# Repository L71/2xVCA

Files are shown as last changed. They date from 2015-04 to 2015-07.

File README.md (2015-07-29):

2 channel VCA module for Eurorack. 

LM13700 based VCA. Two separate channels. 
The VCA CV input is biased to about 8V when no plug is in the CV input (so VCA is open). 

This PCB and front panel drawings are released under the Creative Commons CC-BY-SA 4.0 license.

** Note: the SMD version of the module has the potentionmeters in the opposite direction of the usual. Use knobs that match (or pots with round or T18 shafts).

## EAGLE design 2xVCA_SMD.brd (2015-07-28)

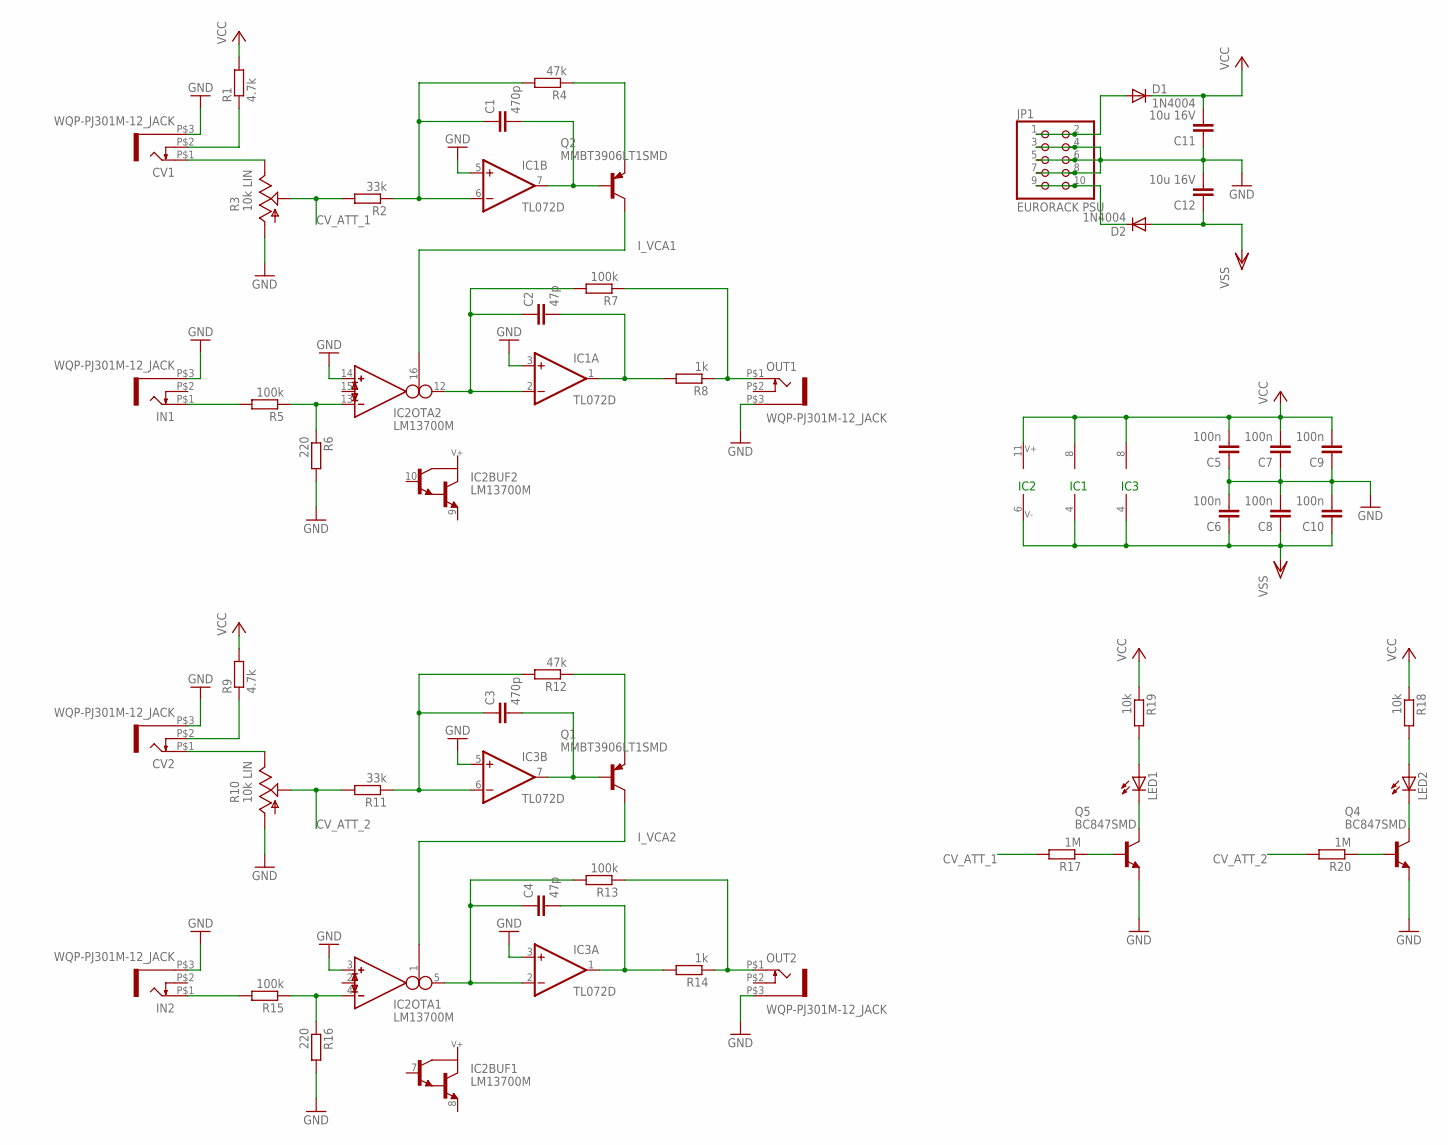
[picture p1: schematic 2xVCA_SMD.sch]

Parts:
C1, C3: 470p; C0603K
C2, C4: 47p; C0603K
C5, C6, C7, C8, C9, C10: 100n; C0603K
C11, C12: 10u 16V; C1206K
CV1, CV2: WQP-PJ301M-12_JACK
D1, D2: 1N4004; DO214AA
IC1, IC3: TL072D; SO08
IC2: LM13700M; SO16
IN1, IN2: WQP-PJ301M-12_JACK
JP1: EURORACK PSU; 2X05
LED1, LED2: LED3MM
OUT1, OUT2: WQP-PJ301M-12_JACK
Q1, Q2: MMBT3906LT1SMD; SOT23-BEC
Q4, Q5: BC847SMD; SOT23
R1, R9: 4.7k; R0603
R2, R11: 33k; R0603
R3, R10: 10k LIN; ALPS_POT_VERTICAL
R4, R12: 47k; R0603
R5, R7, R13, R15: 100k; R0603
R6, R16: 220; R0603
R8, R14: 1k; R0603
R17, R20: 1M; R0603
R18, R19: 10k; R0603

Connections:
CV_ATT_1: R2.2, R3.P$2 (S), R17.2
CV_ATT_2: R10.P$2 (S), R11.2, R20.2
GND: C5.1, C6.2, C7.1, C8.2, C9.1, C10.2, C11.1, C12.2, CV1.P$3 (1), CV2.P$3 (1), IC1.3 (+IN), IC1.5 (+IN), IC2.3 (IN_P), IC2.14 (IN_P), IC3.3 (+IN), IC3.5 (+IN), IN1.P$3 (1), IN2.P$3 (1), JP1.3, JP1.4, JP1.5, JP1.6, JP1.7, JP1.8, OUT1.P$3 (1), OUT2.P$3 (1), Q4.2 (E), Q5.2 (E), R3.P$3 (A), R6.2, R10.P$3 (A), R16.2
I_VCA1: IC2.16 (I_BIAS), Q2.C
I_VCA2: IC2.1 (I_BIAS), Q1.C
unnamed: IN2.P$1 (2), R15.2
unnamed: CV1.P$2 (3), R1.1
unnamed: CV1.P$1 (2), R3.P$1 (E)
unnamed: Q5.1 (B), R17.1
unnamed: C1.1, IC1.6 (-IN), R2.1, R4.2
unnamed: C2.1, IC1.2 (-IN), IC2.12 (OUT), R7.2
unnamed: C1.2, IC1.7 (OUT), Q2.B
unnamed: Q2.E, R4.1
unnamed: IC2.13 (IN_N), R5.1, R6.1
unnamed: IC2.4 (IN_N), R15.1, R16.1
unnamed: IN1.P$1 (2), R5.2
unnamed: C2.2, IC1.1 (OUT), R8.2
unnamed: OUT1.P$1 (2), R7.1, R8.1
unnamed: C4.1, IC2.5 (OUT), IC3.2 (-IN), R13.2
unnamed: CV2.P$2 (3), R9.1
unnamed: CV2.P$1 (2), R10.P$1 (E)
unnamed: LED1.A, R19.2
unnamed: C3.1, IC3.6 (-IN), R11.1, R12.2
unnamed: OUT2.P$1 (2), R13.1, R14.1
unnamed: C3.2, IC3.7 (OUT), Q1.B
unnamed: Q1.E, R12.1
unnamed: C4.2, IC3.1 (OUT), R14.2
unnamed: LED1.K (C), Q5.3 (C)
unnamed: LED2.A, R18.2
unnamed: LED2.K (C), Q4.3 (C)
unnamed: Q4.1 (B), R20.1
unnamed: D1.A, JP1.1, JP1.2
unnamed: D2.C, JP1.9, JP1.10
VCC: C5.2, C7.2, C9.2, C11.2, D1.C, IC1.8 (V+), IC2.11 (V+), IC3.8 (V+), R1.2, R9.2, R18.1, R19.1
VSS: C6.1, C8.1, C10.1, C12.1, D2.A, IC1.4 (V-), IC2.6 (V-), IC3.4 (V-)

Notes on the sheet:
IC1
IC2
IC3

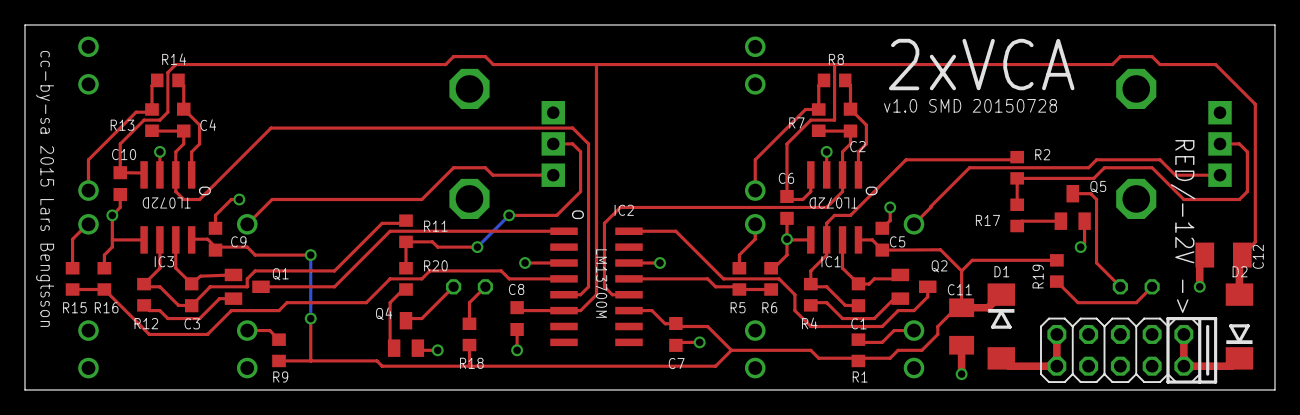
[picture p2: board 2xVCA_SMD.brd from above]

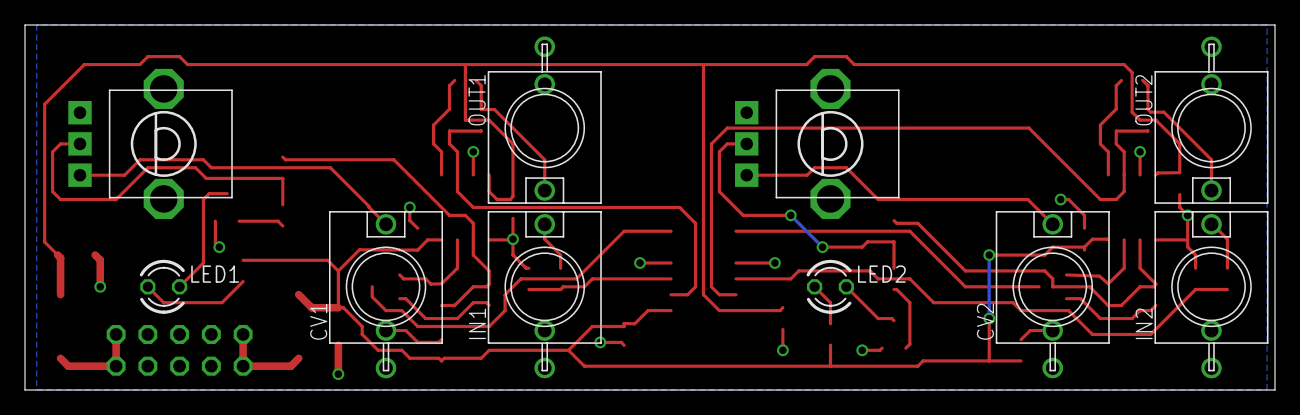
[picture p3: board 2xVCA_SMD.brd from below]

Board: 2 copper layers, 100.0 x 29.2 mm, 50 parts (10 on the bottom side), 35 nets.

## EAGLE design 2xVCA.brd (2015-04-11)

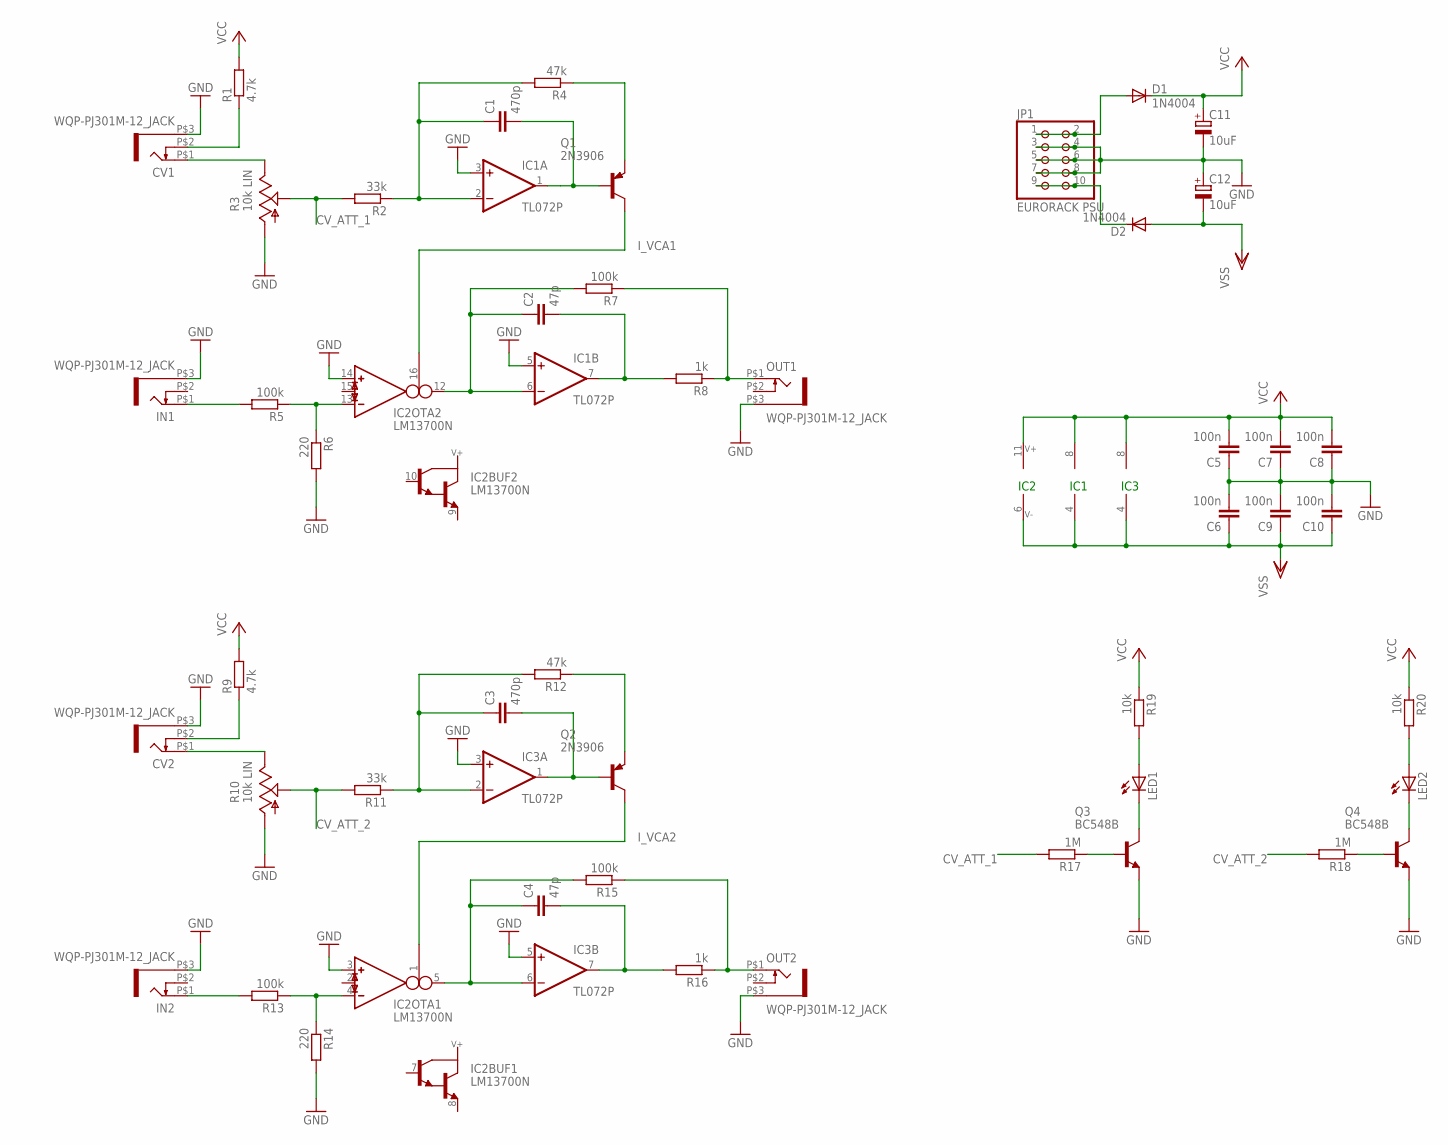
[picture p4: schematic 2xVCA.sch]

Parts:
C1, C3: 470p; C025-025X050
C2, C4: 47p; C025-025X050
C5, C6, C7, C8, C9, C10: 100n; C025-025X050
C11, C12: 10uF; E2,5-5
CV1, CV2: WQP-PJ301M-12_JACK
D1, D2: 1N4004; DO41-10
IC1, IC3: TL072P; DIL08
IC2: LM13700N; DIL16
IN1, IN2: WQP-PJ301M-12_JACK
JP1: EURORACK PSU; 2X05
LED1, LED2: LED3MM
OUT1, OUT2: WQP-PJ301M-12_JACK
Q1, Q2: 2N3906; TO92
Q3, Q4: BC548B; TO92-EBC
R1, R9: 4.7k; 0207/2V
R2, R11: 33k; 0207/2V
R3, R10: 10k LIN; ALPS_POT_VERTICAL
R4, R12: 47k; 0207/2V
R5, R7, R13, R15: 100k; 0207/2V
R6, R14: 220; 0207/2V
R8, R16: 1k; 0207/2V
R17, R18: 1M; 0207/2V
R19, R20: 10k; 0207/2V

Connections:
CV_ATT_1: R2.2, R3.P$2 (S), R17.2
CV_ATT_2: R10.P$2 (S), R11.2, R18.2
GND: C5.1, C6.2, C7.1, C8.1, C9.2, C10.2, C11.-, C12.+, CV1.P$3 (1), CV2.P$3 (1), IC1.3 (+IN), IC1.5 (+IN), IC2.3 (IN_P), IC2.14 (IN_P), IC3.3 (+IN), IC3.5 (+IN), IN1.P$3 (1), IN2.P$3 (1), JP1.3, JP1.4, JP1.5, JP1.6, JP1.7, JP1.8, OUT1.P$3 (1), OUT2.P$3 (1), Q3.E, Q4.E, R3.P$3 (A), R6.2, R10.P$3 (A), R14.2
I_VCA1: IC2.16 (I_BIAS), Q1.1 (C)
I_VCA2: IC2.1 (I_BIAS), Q2.1 (C)
unnamed: IN2.P$1 (2), R13.2
unnamed: CV1.P$2 (3), R1.1
unnamed: CV1.P$1 (2), R3.P$1 (E)
unnamed: Q3.B, R17.1
unnamed: C1.1, IC1.2 (-IN), R2.1, R4.2
unnamed: C2.1, IC1.6 (-IN), IC2.12 (OUT), R7.2
unnamed: C1.2, IC1.1 (OUT), Q1.2 (B)
unnamed: Q1.3 (E), R4.1
unnamed: IC2.13 (IN_N), R5.1, R6.1
unnamed: IC2.4 (IN_N), R13.1, R14.1
unnamed: IN1.P$1 (2), R5.2
unnamed: C2.2, IC1.7 (OUT), R8.2
unnamed: OUT1.P$1 (2), R7.1, R8.1
unnamed: C4.1, IC2.5 (OUT), IC3.6 (-IN), R15.2
unnamed: CV2.P$2 (3), R9.1
unnamed: CV2.P$1 (2), R10.P$1 (E)
unnamed: LED1.A, R19.2
unnamed: C3.1, IC3.2 (-IN), R11.1, R12.2
unnamed: OUT2.P$1 (2), R15.1, R16.1
unnamed: C3.2, IC3.1 (OUT), Q2.2 (B)
unnamed: Q2.3 (E), R12.1
unnamed: C4.2, IC3.7 (OUT), R16.2
unnamed: LED1.K (C), Q3.C
unnamed: LED2.A, R20.2
unnamed: LED2.K (C), Q4.C
unnamed: Q4.B, R18.1
unnamed: D1.A, JP1.1, JP1.2
unnamed: D2.C, JP1.9, JP1.10
VCC: C5.2, C7.2, C8.2, C11.+, D1.C, IC1.8 (V+), IC2.11 (V+), IC3.8 (V+), R1.2, R9.2, R19.1, R20.1
VSS: C6.1, C9.1, C10.1, C12.-, D2.A, IC1.4 (V-), IC2.6 (V-), IC3.4 (V-)

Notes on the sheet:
IC1
IC2
IC3

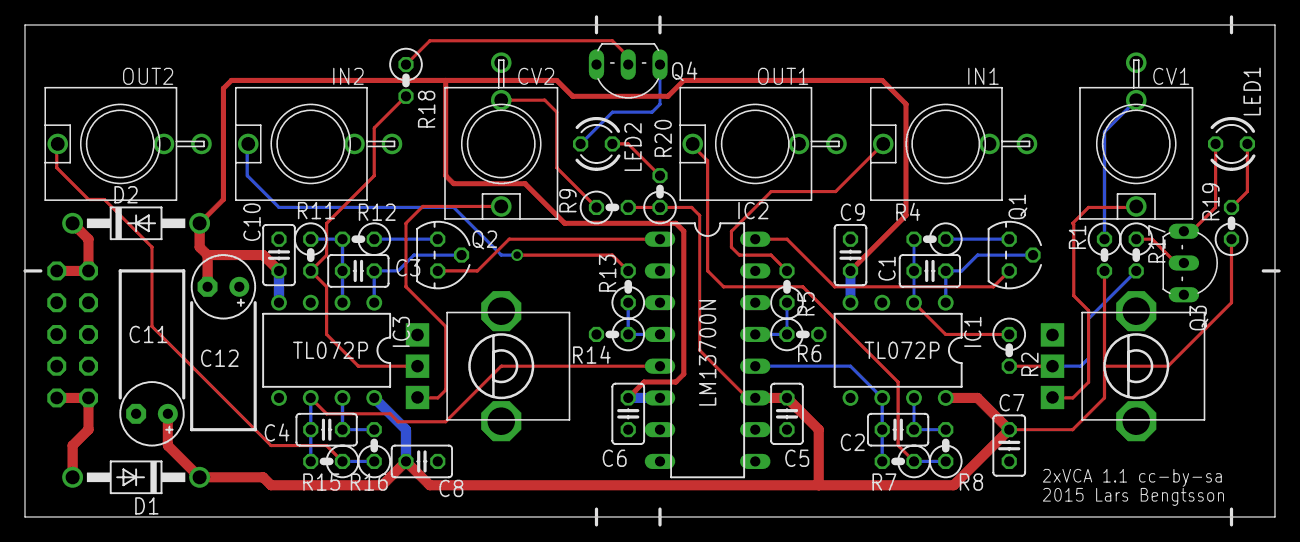
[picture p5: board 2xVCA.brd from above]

Board: 2 copper layers, 100.0 x 39.4 mm, 50 parts (1 on the bottom side), 35 nets.

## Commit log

2015-03-23 Initial add.
    [2xVCA.brd, 2xVCA.sch]
2015-03-23 Moved holes etc up 1/10" (ensure clearance between bottom end of PCB and lower rack rail).
2015-03-29 Added frame at output jacks and moved the text a bit.
2015-04-10 Updated after prototype built.
2015-04-10 Rotated CV input jacks and moved the LEDs a bit. Looks nicer this way.
    [2xVCA.brd]
2015-04-11 Updated component values for use with 10k potentiometers.
    [2xVCA.brd, 2xVCA.sch]
2015-07-28 Initial commit, SMD version, otherwise functinally and electrically identical (6HE wide).
    [2xVCA_SMD.brd, 2xVCA_SMD.sch]
2015-07-28 Fixed component labels. Minor routing adjustments. Spread PSU components a bit. Added board type label & copyright notice.
    [2xVCA_SMD.brd, 2xVCA_SMD.sch]
2015-07-28 Minor routing fixes. Adjusted labels a bit.
    [2xVCA_SMD.brd]
2015-07-28 Rotated T19 to match the rest :)
    [2xVCA_SMD.brd]
2016-01-11 Moved panel bottom edge and holes downwards 1/40" to better fit into racks w 3mm screws. Added engraving indicating the LEDs.

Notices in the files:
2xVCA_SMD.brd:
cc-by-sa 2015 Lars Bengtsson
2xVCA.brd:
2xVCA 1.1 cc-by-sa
